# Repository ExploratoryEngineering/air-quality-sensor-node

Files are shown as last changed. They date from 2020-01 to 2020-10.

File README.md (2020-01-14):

# Air quality sensor node

(work in progress)

GPS enabled NB-IoT Sensor node for sampling NO2, NO, O3 and particulate matter.

## OPC-N3 particle sensor
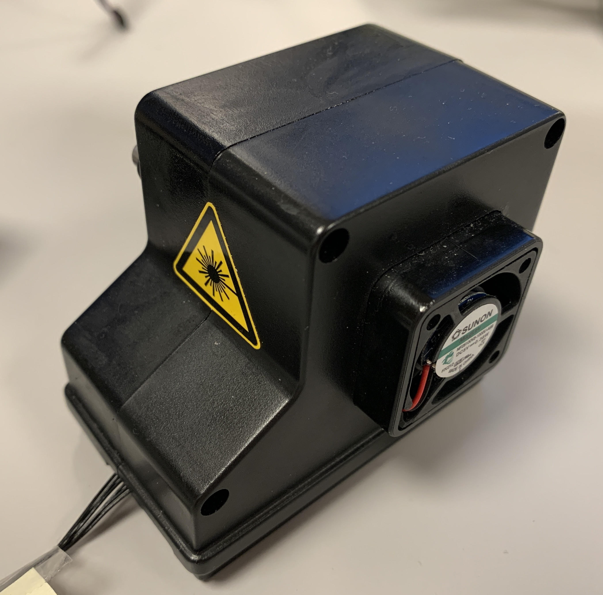
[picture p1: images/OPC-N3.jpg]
OPC-N3 particle sensor


## AFE-3 Analog frontend for NO2, NO and O3 electrochemical sensors
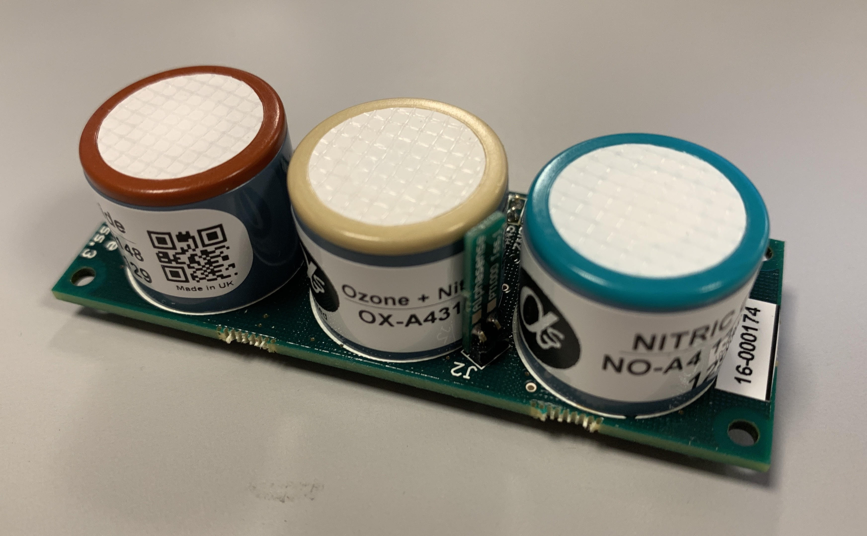
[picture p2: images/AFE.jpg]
Analog frontend and gas sensors


## Vehicle power board
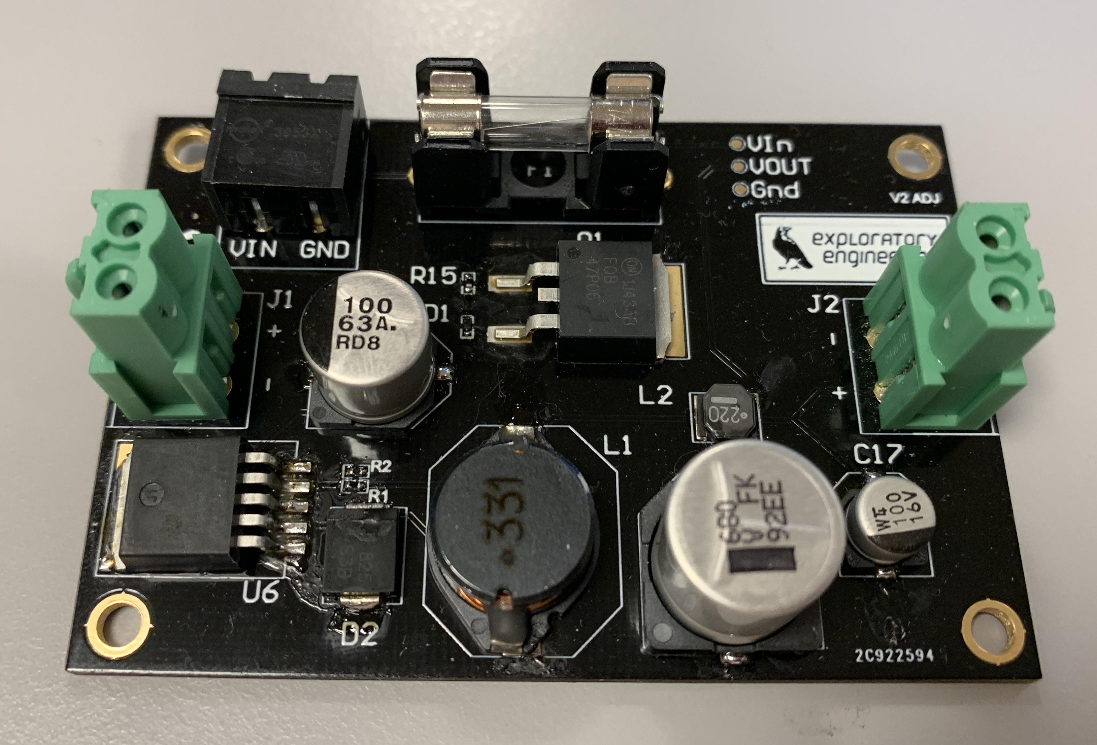
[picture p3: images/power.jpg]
Power board


## EE-NBIoT-02 module
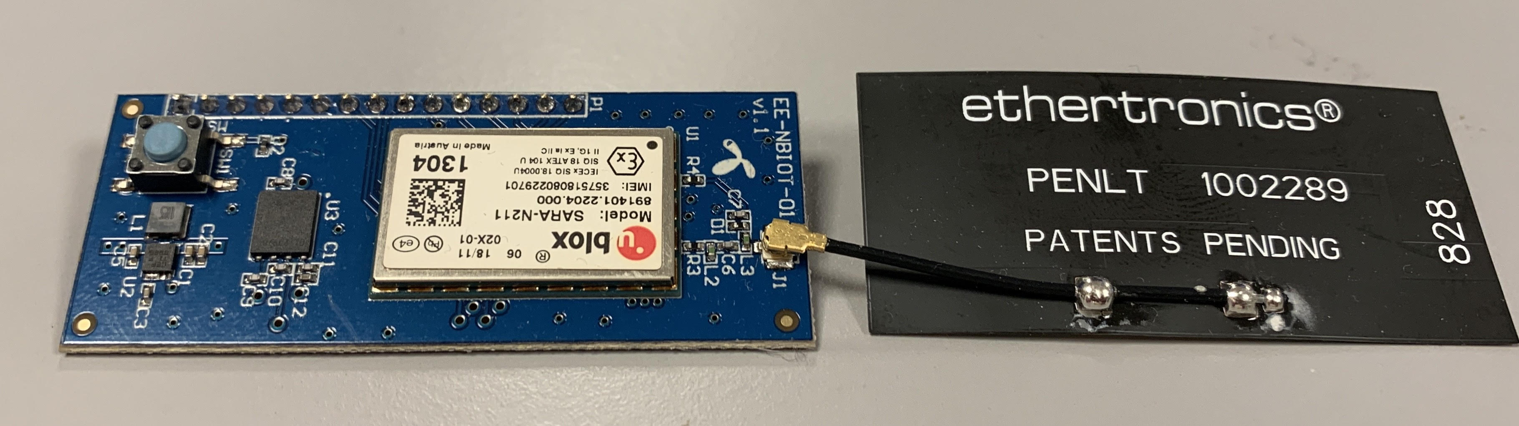
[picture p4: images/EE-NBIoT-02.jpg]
NB-IoT module


## Controller board with nrf52, GPS and ADC
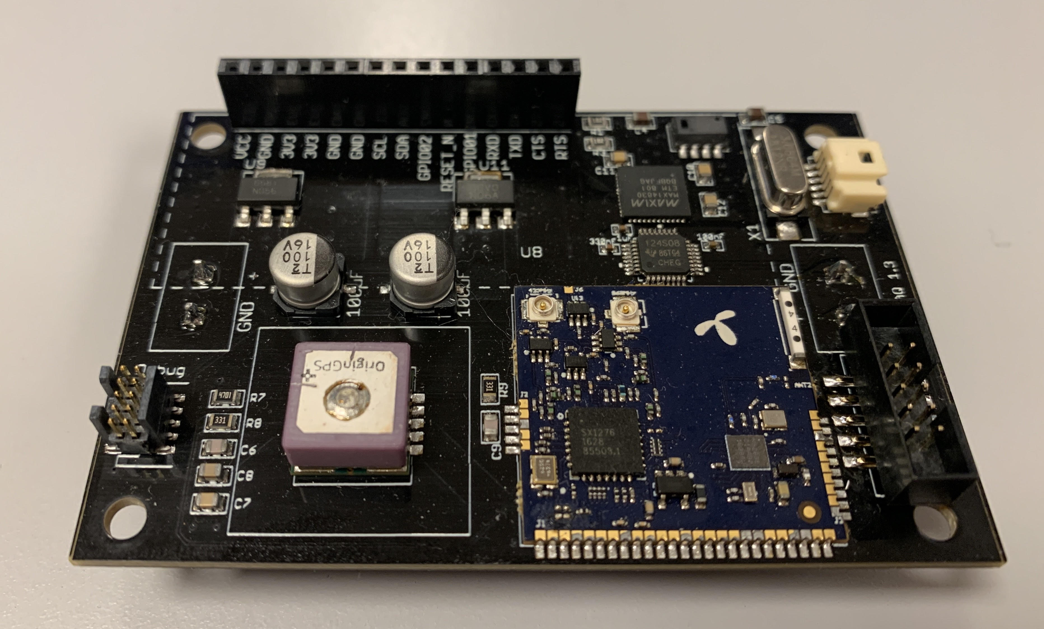
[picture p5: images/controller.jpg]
Controller board


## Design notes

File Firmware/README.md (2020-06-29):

# Air quality sensor node firmware

This project contains firmware for an air quality sensor node

The board is configured for sampling an Alfasense AFE-3 board populated with NO2, NO and O3 sensors, along with temperature, humidity and an OPC-N3 particulate sensor.

Building:

```sh
west update
source ../deps/zephyr/zephyr-env.sh
west build --pristine -b nrf52_pca10040 Firmware
west flash
```
NOTE!  west v0.7 is required for this to work.

## Required tools

To compile protobuf files you need to install protobuf compiler and python bindingds for protobuf.

For MacOS this can be installed with `brew install protobuf` and `pip install protobuf`.
For Linux this can be installed with `apt-get install protobuf-compiler python-protobuf`.

You'll need `make` to build the image. Releases are managed via the `reto` release tool (available at github.com/ExploratoryEngineering/reto)

## Building

You'll need MCUBoot and a key for the application image. If you change the key
you can't deploy the image on existing devices with a different key. A new key
means you'll have to reinstall the bootloader on all your devices.

### Initial setup

Install the "reto" tool:

`go get -u https://github.com/ExploratoryEngineering/reto`

Ensure your Zephyr installation is up and running by running `west build`.

Create a new key and install the bootloader on your device:

```shell
make fwkey
make build_mcuboot
make install_mcuboot
```

### Flashing and debugging

#### Prerequisites

1. Install [JLink](https://www.segger.com/downloads/jlink/) 
2. The ZEPHYR_BASE environment variable has to point to the deps\zephyr
3. Source deps\zephyr\zephyr-env.sh

#### Flashing

1. The target device has to be powered on
2. Connect the EE-04 programmer to a computer via a USB cable
3. Connect the ribbon debug cable between the EE-04 and the target device
4. `make flash`.

#### Debug output

Open a new shell and issue the following command to connect JLink:

```shell
JLinkExe -if swd -device nrf52 -speed 4000 -autoconnect 1
```

Open a second shell and issue the following command to see log output:

```shell
JLinkRTTClient
```

If you have an existing key put it into the `aq_fota.pem` file and skip this step. This is included in `.gitignore` so you won't check it in by accident.

### Message format

The message format uses protobuffers.  You can find these under
**common/protobuf** in this Github repository.  Both the server and
the firmware uses the same protobuffer definition file.

## Enabling FOTA

First commit everything verify the release is read (run `reto status`
to see the current status), the build the release:

`touch CMakeFiles.txt && make`

(this ensures a new build with the updated version number)

Upload firmware image, set version number and assign it to the device in Horde:

```shell
curl -s -HX-API-Token:$(cat .apikey) \
    -XPOST -F image=@build/zephyr/zephyr.signed.bin \
    https://api.nbiot.engineering/collections/$(cat .collectionid)/firmware | jq -r ".imageId" > .firmwareid

curl -XPATCH -d'{"version":"0.0.3"}' -HX-API-Token:$(cat .apikey) \
    https://api.nbiot.engineering/collections/$(cat .collectionid)/firmware/$(cat .firmwareid)

FIRMWAREID=$(cat .firmwareid) curl  -HX-API-Token:$(cat .apikey)\
    -XPATCH -d'{"firmware":{"targetFirmwareId": "${FIRMWAREID}"}}' \
    https://api.nbiot.engineering/collections/$(cat .collectionid)/devices/$(cat .deviceid)

```

Prepare the files `.apikey` with the API token, `.collectionid` and
`.deviceid` with the collection and device ID from Horde. These can be
found and/or created in [The Horde console](https://nbiot.engineering)

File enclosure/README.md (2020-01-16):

# Air quality sensor node

(work in progress)

GPS enabled NB-IoT Sensor node for sampling NO2, NO, O3 and particulate matter. 

# Internal structure (preliminary)

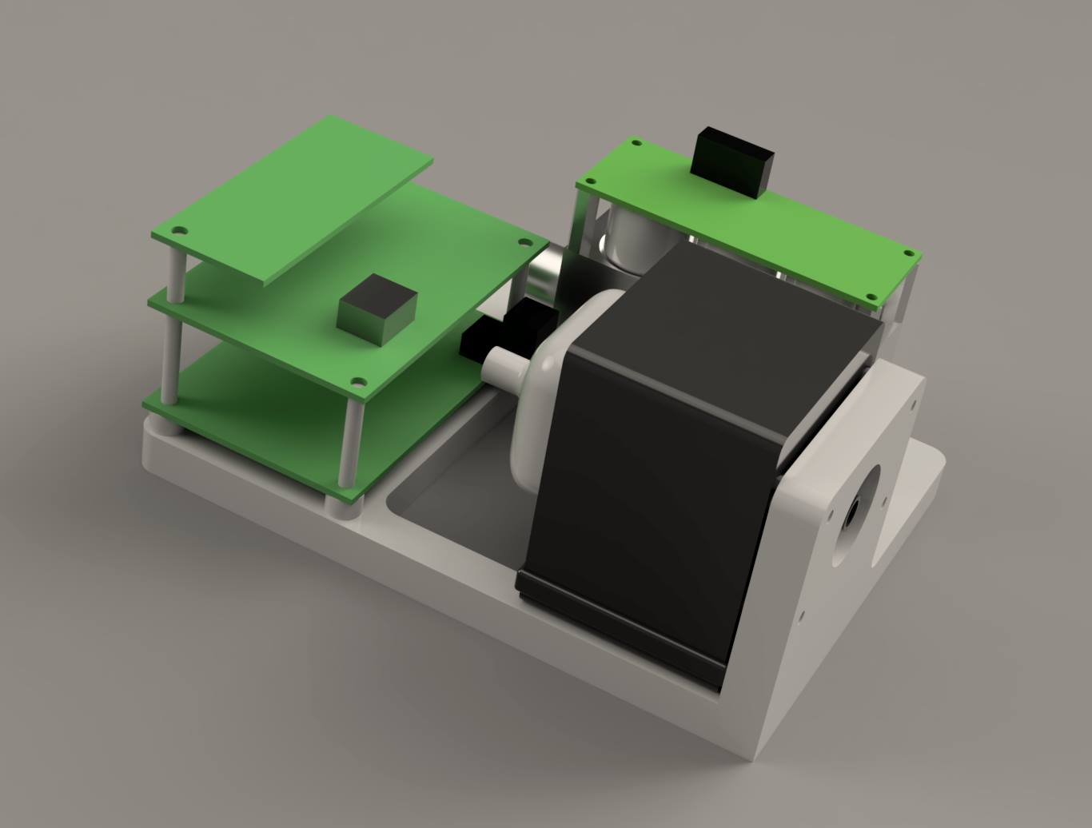
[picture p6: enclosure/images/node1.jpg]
node1


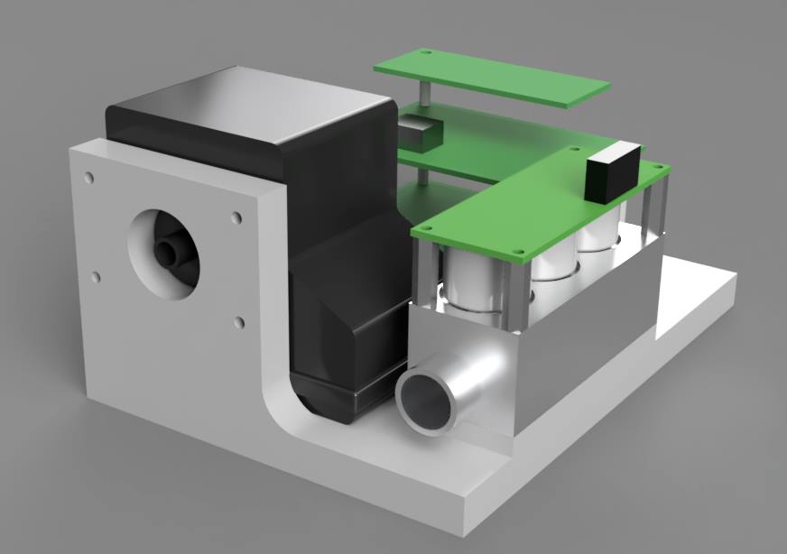
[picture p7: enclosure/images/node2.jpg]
node2


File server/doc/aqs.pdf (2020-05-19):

# AQS Documentation

AQS Documentation

## Contents

Introduction | 3
Building AQS | 5
AQS Usage | 7
Sensors | 8

2

AQS Documentation

## Introduction

The Air Quality Server (AQS) is a lightweight tool that can be used to receive, store and serve air quality data from the third generation air quality sensor from Exploratory Engineering. It can both be run as a more permanent server in a datacenter in order to receive, process, store and pass on data, but it is also designed for ad-hoc experimentation by researchers and integrators. Some care has been taken in order to make both scenarios possible. It should be trivial to download, build and run the server on your personal machine, as well as running it in a datacenter.

Data reception

Currently the server supports two different ways of receiving data - you can either configure it to connect to IoT-GW/Horde and have it listen to the data stream belonging to a given collection.

We are also in the process of developing a solution that will allow the server to use MIC as the source of messages, but this is not supported at the time of writing.

For experimentation purposes it is also possible to use a UDP-based protocol for injecting messages into a running server.

Database storage

The AQS makes use of a local SQLite 3 database where it stores calibration data as well as the messages (datapoints) it has received from the network. We chose to use SQLite 3 as the database as a convenience because the data rates and amounts of data are fairly modest for the number of sensors we are dealing with. At some later point we may support PostgreSQL so that the Air Quality Server can deal with higher volumes.

The choice of embedding the database was made to make life simpler for researchers and people who simply want to experiment with the system, as there is no need to set up and manage a separate database system. Everything is taken care of by the server. The database itself is located in a single file, which makes it easy to copy the data around and perform ad-hoc queries on it using the sqlite3 command line utility.

Open source

The AQS is published under the Apache 2.0 license, and you are encouraged to contribute to its development. Bug reports and feature requests filed through the issue tracking on the Github project

3

AQS Documentation

are welcome. Pull requests with code are even more welcome. The Git repository is located at https: //github.com/exploratoryengineering/air-quality-sensor-node.

4

AQS Documentation

## Building AQS

Check out source from Github

The AQS is hosted on Github at and you can clone it by issuing the command:

git clone https://github.com/ExploratoryEngineering/air-quality-sensor-node.git

This will copy not only the server, but also the hardware designs for the sensor, the firmware source code for the device, and the server. In order to build the server change directory to the server directory.

Fetch dependencies

- Go 1.14 or newer
- Protobuf Compiler version 3.0.0 or newer
- Protobuf Code generator for Go
- SQLite3 libraries

Installing Go

For information on how to install Go, please refer to https://golang.org/doc/install.

Installing Protobuf

To install the protobuf compiler on macOS the easiest route is to use Homebrew and install it with:

brew install protobuf

or on Linux

apt install protobuf-compiler

You then need to install the protobuf code generator for Go, which you can install with the command, which should work on all platforms Go has been ported to:

go install google.golang.org/protobuf/cmd/protoc-gen-go

Installing libsqlite3

On macOS you can install the latest SQLite version (including libraries) using

5

AQS Documentation

brew install sqlite

On Linux you can do this with

apt install libsqlite3-dev

Building AQS with make

We use make to build the server. Per default the Makefile is set up to build the server for macOS. You can either edit the Makefile and change the default valuesfor GOOS and GOARCH tofit the platform you are building on, or you can specify these variables on the command line.

For instance in order to build for Linux you would

GOOS=linux GOARCH=amd64 make

This should produce a bin directory containing a runnable binary called ac. To test that you have succeeded in building it you can run bin/aq and it should produce output that looks something like this:

$ bin/aq -h
Usage:
aq [OPTIONS] <command>

Application Options:
-c, --collection=<collectionID> | Horde collection id to listen to (default: 17dh0cf43jg007)
-d, --db=<file> | Data storage file (default: aq.db)
-v, --verbose

Help Options:
-h, --help | Show this help message

Available commands:
convert Convert calibration data
fetch | Fetch historical data
import | Import a calibration data
list | List calibration data
rm | Remove calibration data
run | Run server
show | Show calibration data for device

6

AQS Documentation

## AQS Usage

** Usage doc **

7

AQS Documentation

## Sensors

Alphasense OPC-N3

For measuring amount of particulate matter present in the air, we use the OPC-N3 (http://www.alphasense.com/index.php/products/optical-particle-counter/) sensor from Alphasense. (http://www.alphasense.com/) This sensor can measure particles from 0.35μm to 40 μm and it will report these in 24 ranges or “bins”. The particle size ranges for each bin can be found in the table on the next page.

8

AQS Documentation

bin from (µm) to (µm)

0 | 0.35 | 0.46
1 | 0.46 | 0.66
2 | 0.66 | 1.0
3 | 1.0 | 1.3
4 | 1.3 | 1.7
5 | 1.7 | 2.3
6 | 2.3 | 3.0
7 | 3.0 | 4.0
8 | 4.0 | 5.2
9 | 5.2 | 6.5
10 | 6.5 | 8.0
11 | 8.0 | 10.0
12 | 10.0 | 12.0
13 | 12.0 | 14.0
14 | 14.0 | 16.0
15 | 16.0 | 18.0
16 | 18.0 | 20.0
17 | 20.0 | 22.0
18 | 22.0 | 25.0
19 | 25.0 | 28.0
20 | 28.0 | 31.0
21 | 31.0 | 34.0
22 | 34.0 | 37.0
23 | 37.0 | 40.0

9

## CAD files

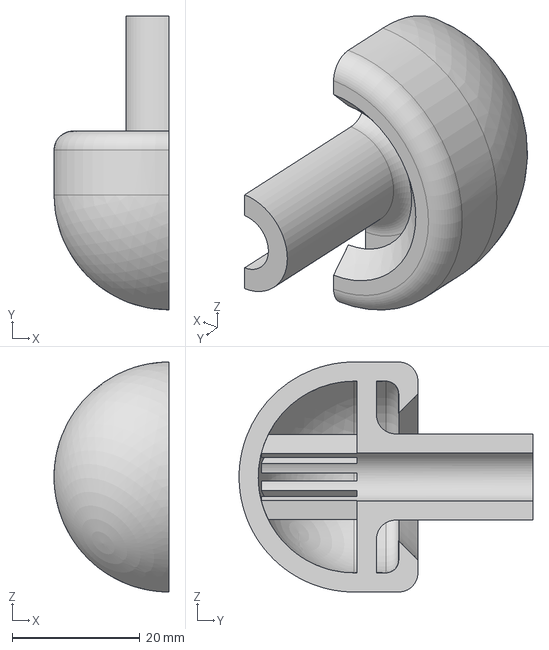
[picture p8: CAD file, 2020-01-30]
enclosure/nozzles/nozzle_bottom.step
18.0 x 46.0 x 36.0 mm

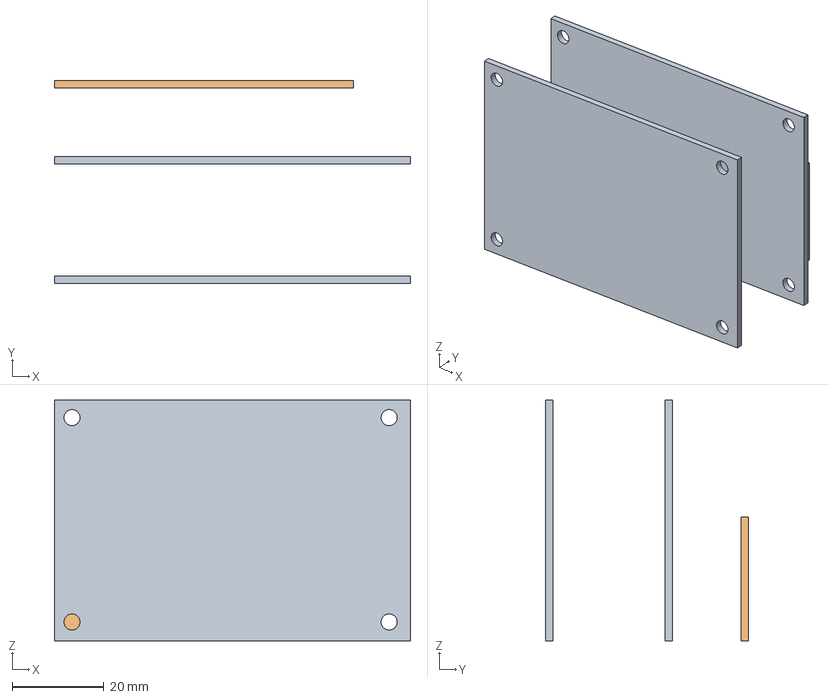
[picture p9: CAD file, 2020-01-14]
enclosure/pcb_stack/SensorPCB_stack.step
77.5 x 44.2 x 52.4 mm
Power board
Sensor Board
EE-NBIOT-01

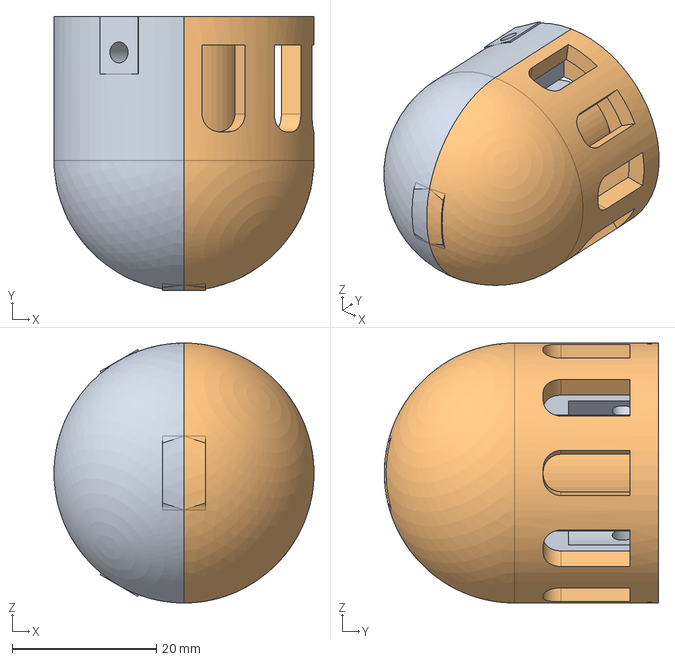
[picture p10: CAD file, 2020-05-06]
enclosure/STEP/PP_Gas_intake.step
36.0 x 38.0 x 36.0 mm
part_b

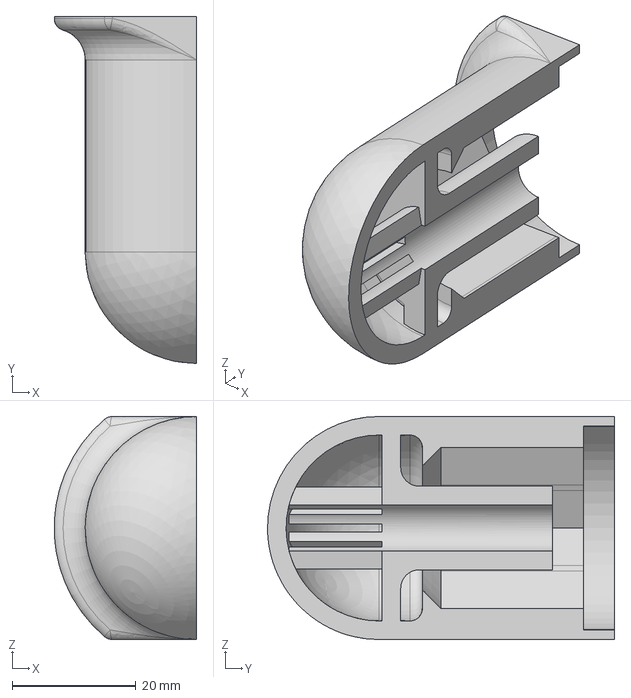
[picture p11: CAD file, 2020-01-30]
enclosure/nozzles/nozzle_top.step
23.0 x 56.0 x 36.0 mm

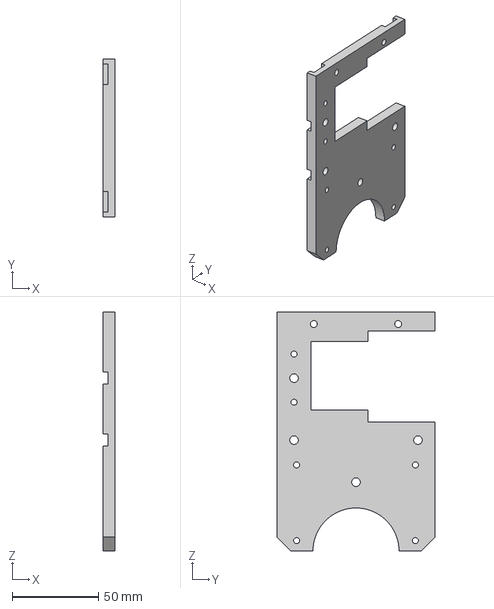
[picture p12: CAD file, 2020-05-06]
enclosure/STEP/PLA_Sensor_frame.step
7.00 x 92.0 x 138.8 mm

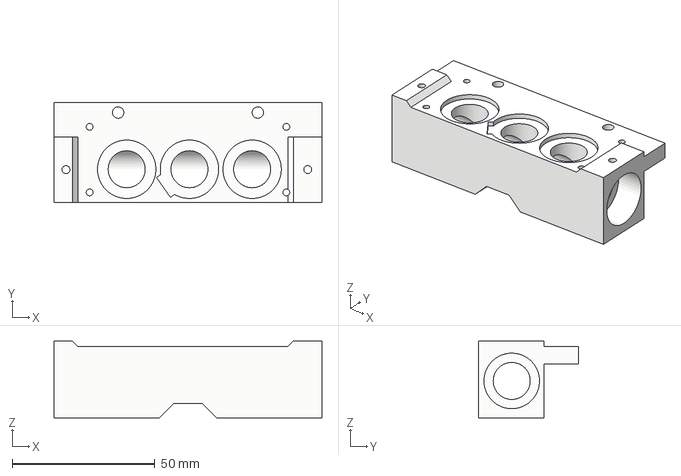
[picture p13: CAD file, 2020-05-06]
enclosure/STEP/PP_AFE_mounting_block.step
94.0 x 35.0 x 27.0 mm

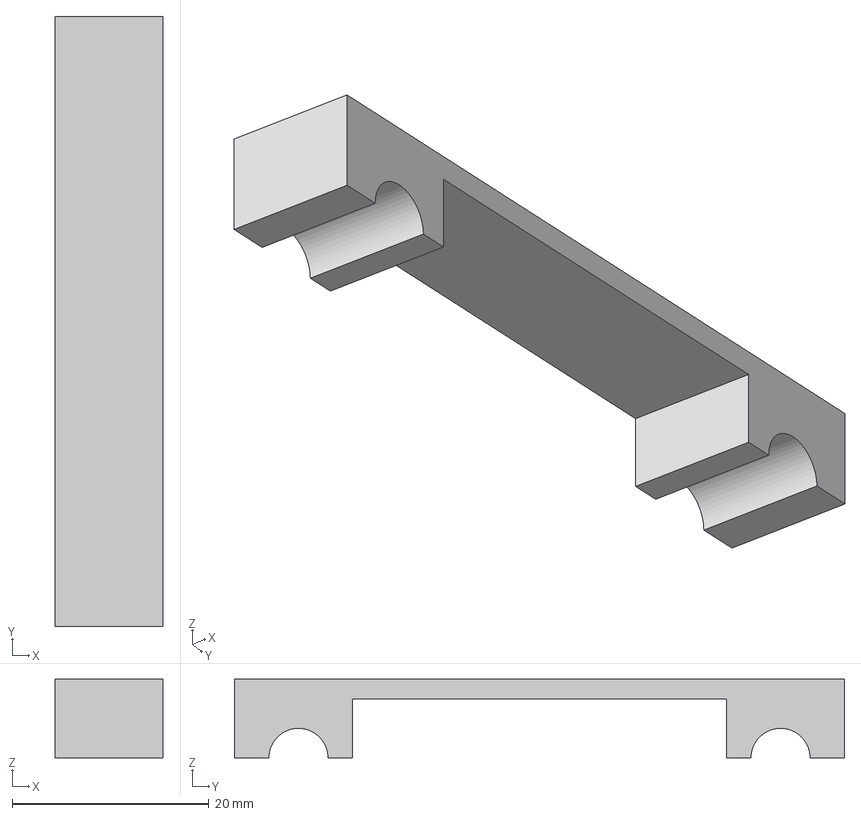
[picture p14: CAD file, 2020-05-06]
enclosure/STEP/PLA_AFE_spacer.step
11.0 x 62.0 x 8.00 mm

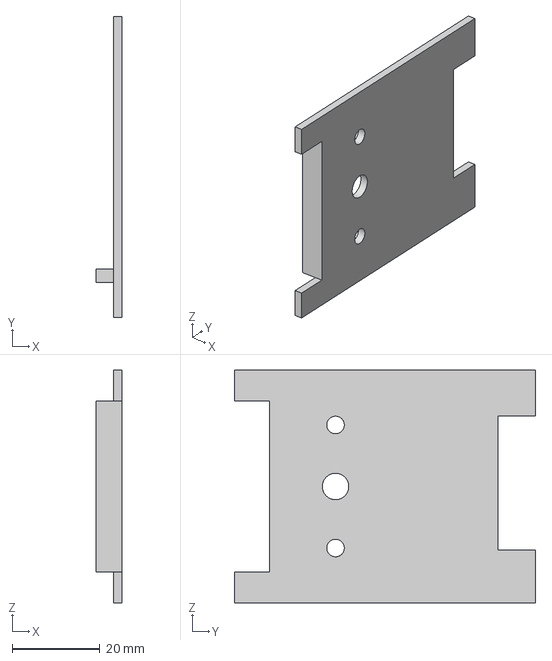
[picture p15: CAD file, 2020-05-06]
enclosure/STEP/PLA_OPC_hood_b.step
6.00 x 68.5 x 53.0 mm

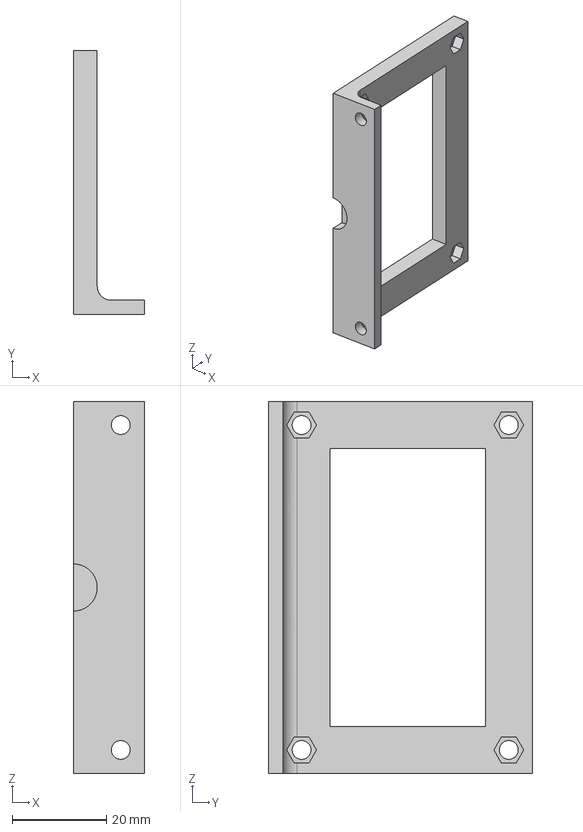
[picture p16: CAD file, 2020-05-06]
enclosure/STEP/PLA_PCB_bracket.step
15.0 x 56.0 x 79.0 mm

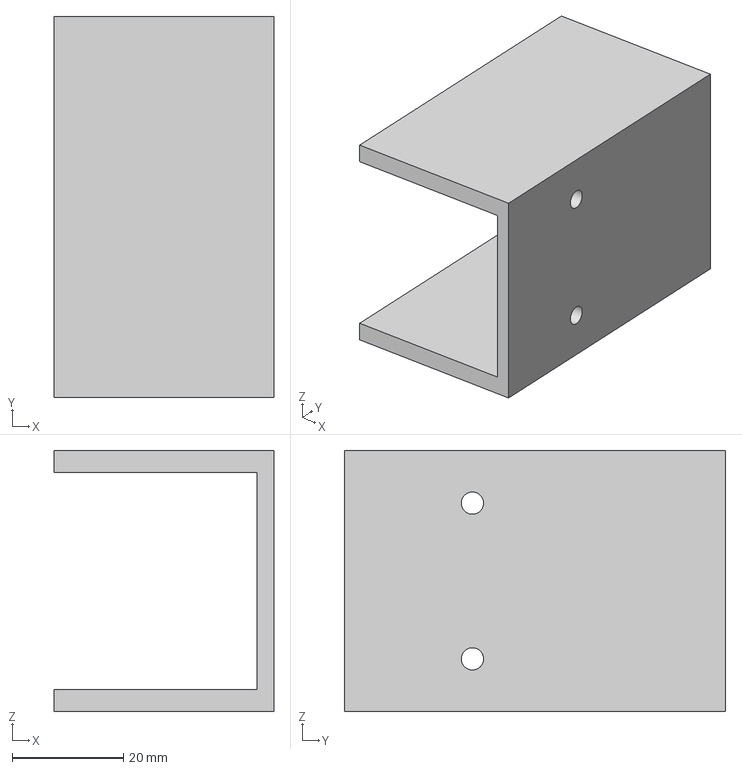
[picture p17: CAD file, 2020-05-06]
enclosure/STEP/PLA_OPC_hood_a.step
39.5 x 68.5 x 47.0 mm

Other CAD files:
enclosure/STEP/PLA_Particle_intake_a.step
enclosure/STEP/PLA_Particle_intake_b.step
enclosure/STL/PLA_AFE_spacer.stl
enclosure/STL/PLA_OPC_hood_a.stl
enclosure/STL/PLA_OPC_hood_b.stl
enclosure/STL/PLA_PCB_bracket.stl
enclosure/STL/PLA_Particle_intake_a.stl
enclosure/STL/PLA_Particle_intake_b.stl
enclosure/STL/PLA_Sensor_frame.stl
enclosure/STL/PP_AFE_mounting_block.stl
enclosure/STL/PP_Gas_intake.stl
enclosure/assembly/Alphasense-A4-AFE-3-way.f3d
enclosure/assembly/OPC-N3.f3d
enclosure/assembly/TP-electric-3310-217-0600.f3d
enclosure/assembly/assembly-2-v10.f3z

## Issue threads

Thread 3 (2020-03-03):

Create server with local database storage

borud, 2020-03-03:
Accept `Sample` messages from Horde and store them to a database.
- [x] Create initial protobuf schema
- [x] Create SQL schema
- [x] Create Horde listener
- [x] Create UDP listener
- [x] Create processing pipeline
- [x] Create simple websockets listener
- [x] Pull older samples from Horde and store them locally

pkkummermo, 2020-03-04:
A lot of inspiration can be taken from https://github.com/ExploratoryEngineering/tkaq as it solves the exact same use case.

borud, 2020-03-08:
@pkkummermo I intend to ste...borrow liberally :-)

Closed 2020-04-06.

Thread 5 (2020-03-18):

Store calibration data in database

borud, 2020-03-18:
- [x] Add table for storing calibration data
- [x] Create import utility that can read calibration data from CSV or JSON
- [ ] Create web interface to add calibration data via browser
- [x] Experiment with OCR of calibration sheets if we can't get calibration data from there (combine with web interface)

borud, 2020-03-29:
Implemented reading calibration data from CSV files that look a bit funky.  Need a better format, but fix that later.

Closed 2020-03-29.

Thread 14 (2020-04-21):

Rewrite calibration data caching logic

borud, 2020-04-21:
Today there's a half baked calibration data cache which is in the wrong place.  Move the caching to the persistence layer.

There should also be a mechanism for detecting if the calibration data has been changed "under our feet" by someone directly modifying the database and trigger a reload.

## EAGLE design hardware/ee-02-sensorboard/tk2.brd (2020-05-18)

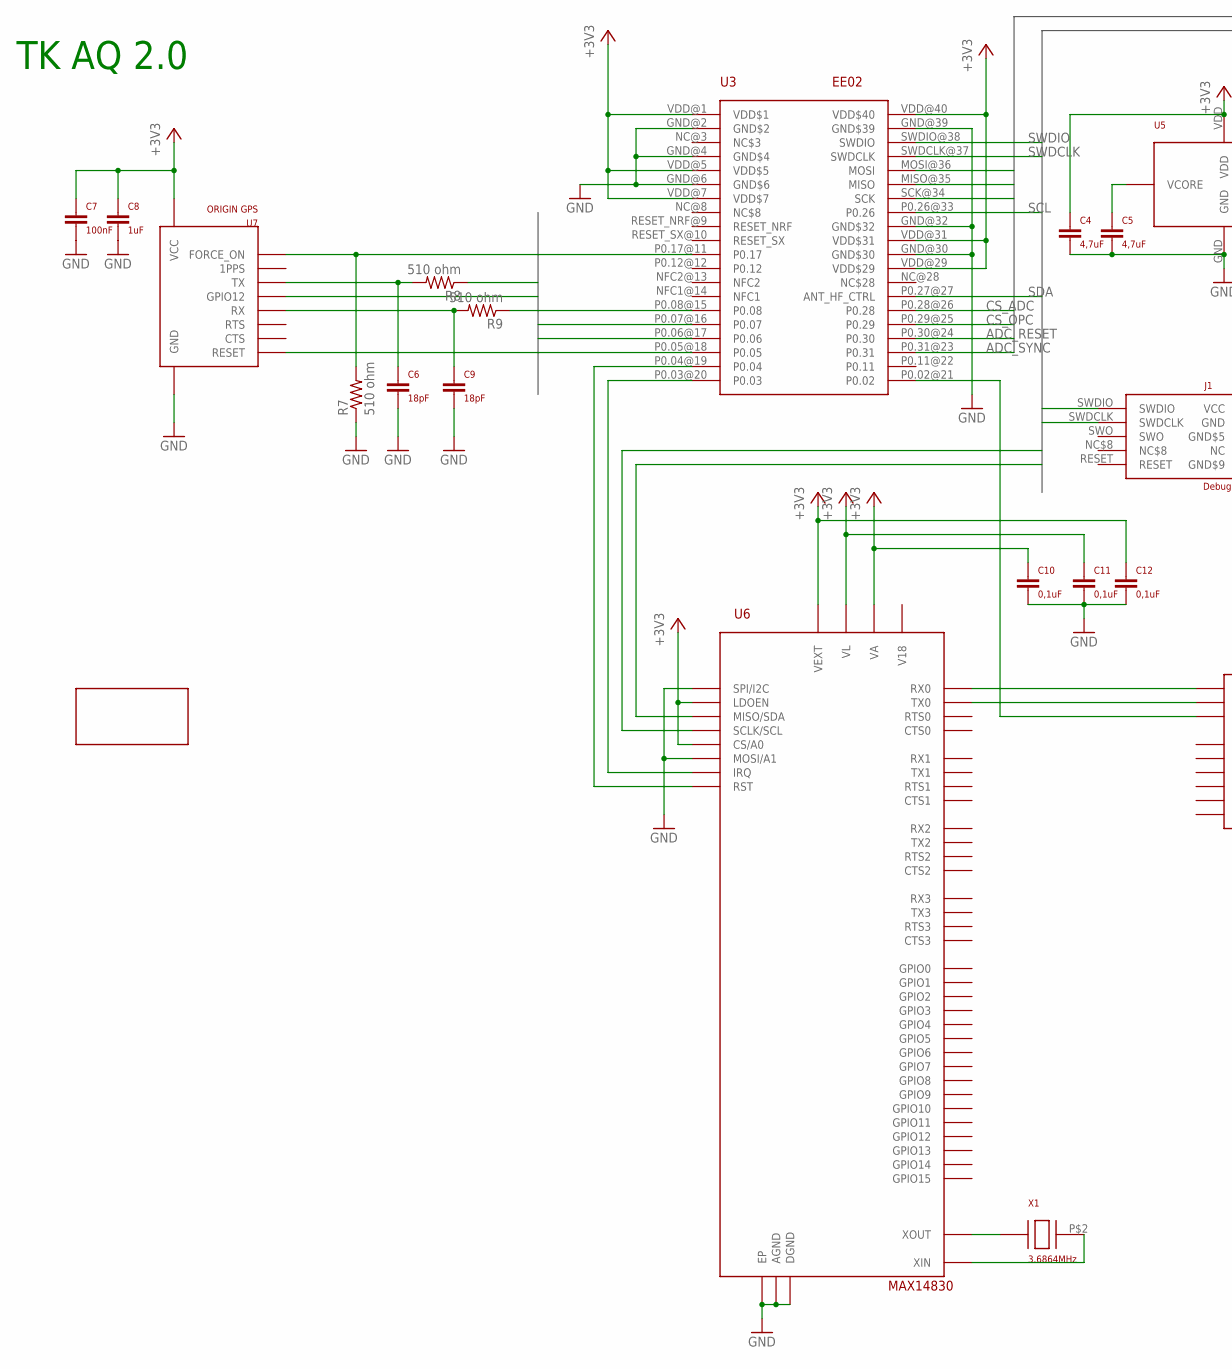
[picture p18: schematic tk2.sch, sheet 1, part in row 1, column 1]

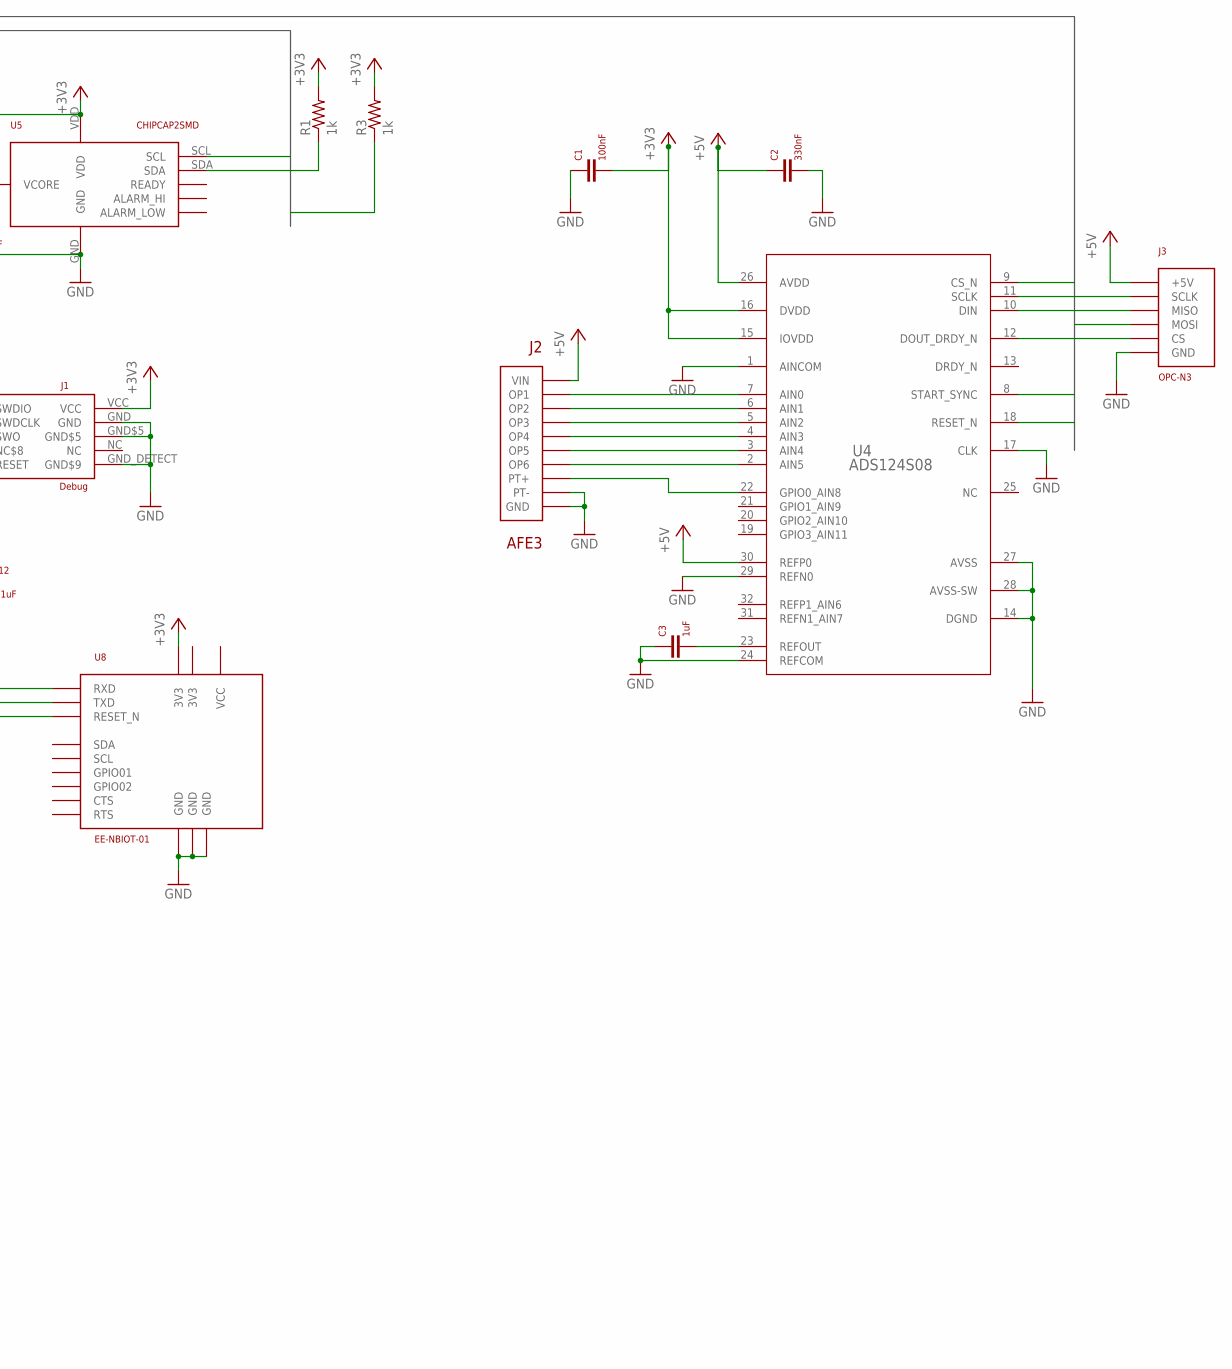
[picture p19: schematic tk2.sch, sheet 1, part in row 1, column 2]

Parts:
C1: 100nF; 0402
C2: 330nF; 0402
C3: 1uF; 0402
C4, C5: 4,7uF; 0805
C6, C9: 18pF; 0805
C7: 100nF; 0805
C8: 1uF; 0805
C10, C11, C12: 0,1uF; 0805
J1: Debug; NRF52-P19-CONNECTOR
J2: AFE3_IDC_CABLE
J3: OPC_N3_CONNECTOR
R1, R3: 1k; 0805
R7, R8, R9: 510 ohm; 0805
U3: EE02; EE02_02
U4: ADS124S08; PBS0032A_N
U5: CHIPCAP2SMD; CHIPCAP2
U6: MAX14830
U7: ORIGIN GPS; ORIGIN_GPS_HORNET_1510
U8: EE-NBIOT-01
U$1: EE_TK_LOGO
X1: CRYSTAL_HC49

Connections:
+3V3: C1.2, C4.1, C7.1, C8.1, C10.1, C11.1, C12.1, J1.VCC, R1.2, R3.2, U3.VDD@1 (VDD$1), U3.VDD@5 (VDD$5), U3.VDD@7 (VDD$7), U3.VDD@29 (VDD$29), U3.VDD@31 (VDD$31), U3.VDD@40 (VDD$40), U4.15 (IOVDD), U4.16 (DVDD), U5.VDD, U6.CS/A0, U6.LDOEN, U6.VA, U6.VEXT, U6.VL, U7.4_VCC (VCC), U8.3V3@3 (3V3); also elsewhere on the board
+5V: C2.1, J2.VIN, J3.+5V, U4.26 (AVDD), U4.30 (REFP0); also elsewhere on the board
ADC_RESET: U3.P0.30@24 (P0.30), U4.18 (RESET_N)
ADC_SYNC: U3.P0.31@23 (P0.31), U4.8 (START_SYNC)
CS_ADC: U3.P0.28@26 (P0.28), U4.9 (CS_N)
CS_OPC: J3.CS, U3.P0.29@25 (P0.29)
FORCE_ON: R7.2, U3.P0.17@11 (P0.17), U7.1_FORCE_ON (FORCE_ON)
GND: C1.1, C2.2, C3.1, C4.2, C5.2, C6.2, C7.2, C8.2, C9.2, C10.2, C11.2, C12.2, J1.GND, J1.GND$5, J1.GND_DETECT (GND$9), J2.GND, J2.PT-, J3.GND, R7.1, U3.GND@2 (GND$2), U3.GND@4 (GND$4), U3.GND@6 (GND$6), U3.GND@30 (GND$30), U3.GND@32 (GND$32), U3.GND@39 (GND$39), U4.1 (AINCOM), U4.14 (DGND), U4.17 (CLK), U4.24 (REFCOM), U4.27 (AVSS), U4.28 (AVSS-SW), U4.29 (REFN0), U5.GND, U6.AGND, U6.DGND, U6.EP, U6.MOSI/A1, U6.SPI/I2C, U7.5_GND (GND), U8.GND@2 (GND), U8.GND@5 (GND), U8.GND@6 (GND); also elsewhere on the board
MISO: J3.MISO, U3.MISO@35 (MISO), U4.12 (DOUT_DRDY_N)
MOSI: J3.MOSI, U3.MOSI@36 (MOSI), U4.10 (DIN)
unnamed: C5.1, U5.VCORE
unnamed: C3.2, U4.23 (REFOUT)
unnamed: U6.RX0, U8.RXD
unnamed: U6.TX0, U8.TXD
unnamed: C6.1, R8.2, U7.3_TX (TX)
unnamed: C9.1, R9.2, U7.10_RX (RX)
unnamed: J2.OP1, U4.7 (AIN0)
unnamed: J2.OP2, U4.6 (AIN1)
unnamed: J2.OP3, U4.5 (AIN2)
unnamed: J2.OP4, U4.4 (AIN3)
unnamed: U3.P0.03@20 (P0.03), U6.IRQ
unnamed: U3.P0.04@19 (P0.04), U6.RST
unnamed: U3.P0.02@21 (P0.02), U8.RESET_N
unnamed: U6.XOUT, X1.P$1
unnamed: U6.XIN, X1.P$2
unnamed: J2.OP5, U4.3 (AIN4)
unnamed: J2.OP6, U4.2 (AIN5)
unnamed: J2.PT+, U4.22 (GPIO0_AIN8)
RESET: U3.P0.06@17 (P0.06), U7.8_RESET (RESET)
RX: R9.1, U3.P0.07@16 (P0.07)
SCL: R1.1, U3.P0.26@33 (P0.26), U5.SCL, U6.SCLK/SCL
SCLK: J3.SCLK, U3.SCK@34 (SCK), U4.11 (SCLK)
SDA: R3.1, U3.P0.27@27 (ANT_HF_CTRL), U5.SDA, U6.MISO/SDA
SWDCLK: J1.SWDCLK, U3.SWDCLK@37 (SWDCLK)
SWDIO: J1.SWDIO, U3.SWDIO@38 (SWDIO)
TX: R8.1, U3.P0.08@15 (P0.08)
WAKE_UP: U3.P0.05@18 (P0.05), U7.6_GPIO12 (GPIO12)

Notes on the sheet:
TK AQ 2.0

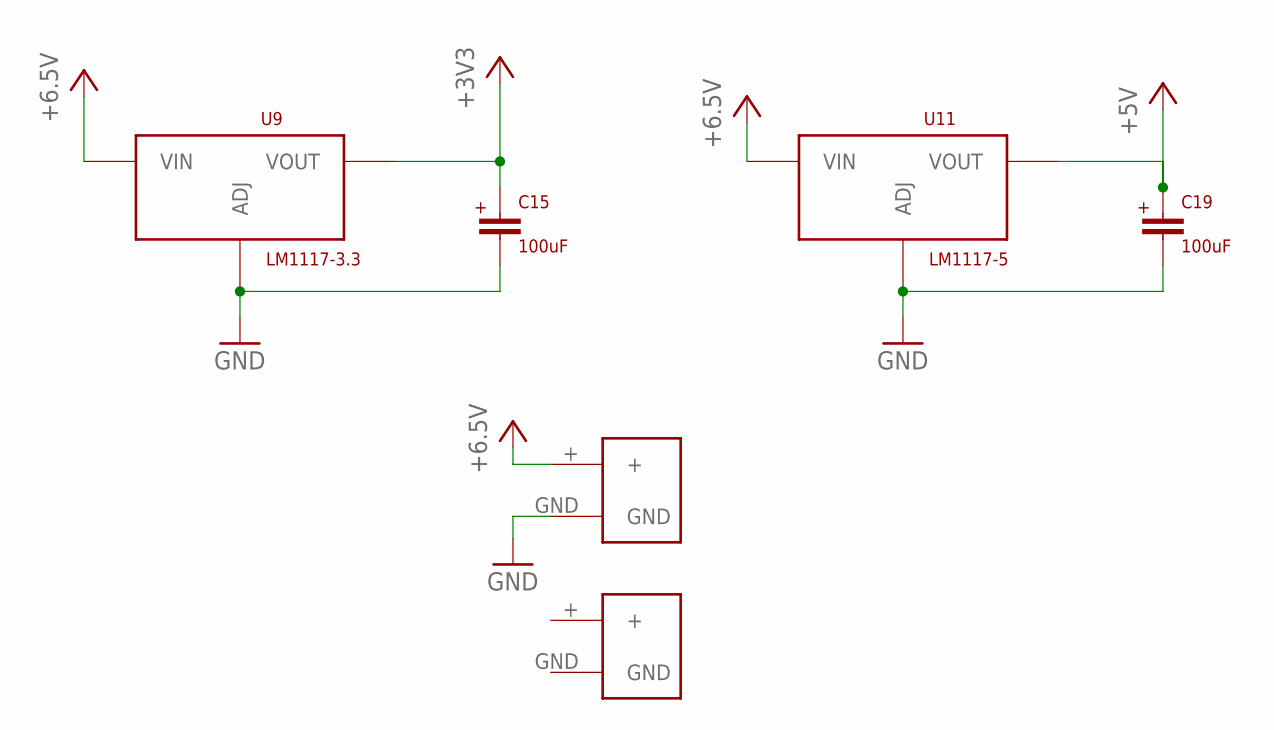
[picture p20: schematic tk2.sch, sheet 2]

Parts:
C15, C19: 100uF; ALUMINUM_WURTH_100UF_865080243007
U9: LM1117-3.3; LM1117
U11: LM1117-5; LM1117
U$2, U$3: PHOENIX_CONTACT_MSTBVA_2_5

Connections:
+3V3: C15.+, U9.VOUT$1 (VOUT), U9.VOUT$2 (VOUT); also elsewhere on the board
+5V: C19.+, U11.VOUT$1 (VOUT), U11.VOUT$2 (VOUT); also elsewhere on the board
+6.5V: U9.VIN, U11.VIN, U$2.+
GND: C15.-, C19.-, U9.GND (ADJ), U11.GND (ADJ), U$2.GND; also elsewhere on the board

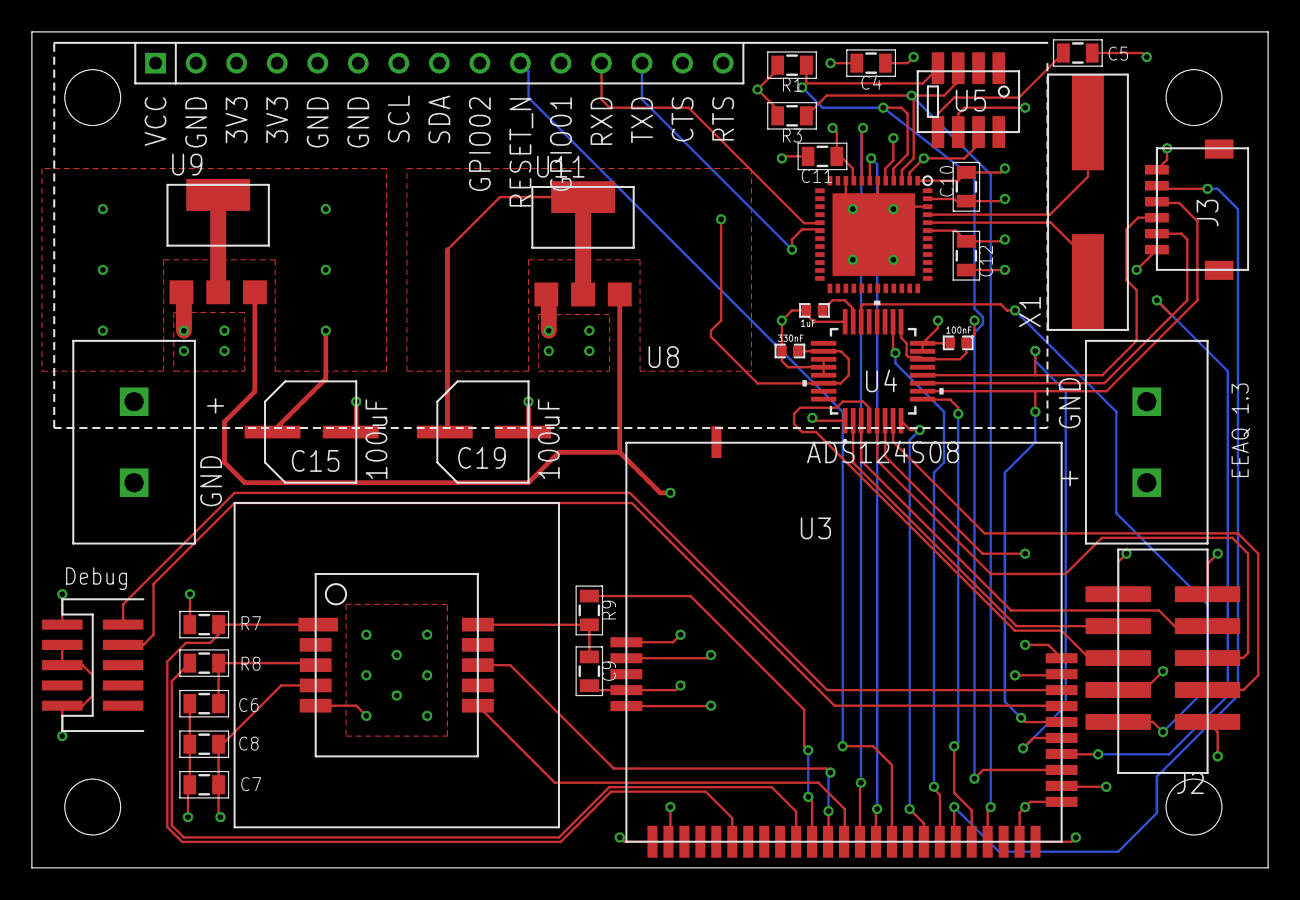
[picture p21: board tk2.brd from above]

Board: 4 copper layers, 77.5 x 52.4 mm, 34 parts (1 on the bottom side), 38 nets.

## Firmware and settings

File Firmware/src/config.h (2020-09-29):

#ifndef _CONFIG_H_
#define _CONFIG_H_

#define APN_QUERY_RETRY_COUNT 	30
#define APN_RETRY_DELAY_MS		3000	

#define PING_RETRIES            30
#define PING_RETRY_DELAY_MS		3000	

#define NVS_APN_COUNT 4

// Default COAP parameters
#define DEFAULT_FOTA_COAP_REPORT_PATH   "u"
#define DEFAULT_FOTA_COAP_UPDATE_PATH   "fw"
#define DEFAULT_FOTA_COAP_PORT 5683

// Force reboot after 2 hours. This wil trigger a new scan for active APNs
#define UPTIME_FORCE_REBOOT_LIMIT_SECONDS 60 * 120

#include "config_message.h"
#include "aqconfig.pb.h"

void init_config_nvs();
void select_active_apn();
bool select_ping_apn();
int save_apn_config();

#endif // _CONFIG_H_

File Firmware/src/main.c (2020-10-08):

/*
**   Copyright 2020 Telenor Digital AS
**
**  Licensed under the Apache License, Version 2.0 (the "License");
**  you may not use this file except in compliance with the License.
**  You may obtain a copy of the License at
**
**      http://www.apache.org/licenses/LICENSE-2.0
**
**  Unless required by applicable law or agreed to in writing, software
**  distributed under the License is distributed on an "AS IS" BASIS,
**  WITHOUT WARRANTIES OR CONDITIONS OF ANY KIND, either express or implied.
**  See the License for the specific language governing permissions and
**  limitations under the License.
*/

#include <zephyr.h>
#include <stdio.h>
#include <logging/log.h>
#include <net/socket.h>
#include <misc/reboot.h>
#include <drivers/watchdog.h>

#include "gps.h"
#include "messagebuffer.h"
#include "version.h"
#include "init.h"
#include "chipcap2.h"
#include "n2_offload.h"
#include "fota.h"
#include "comms.h"
#include "config.h"
#include "config_message.h"


#define LOG_LEVEL CONFIG_MAIN_LOG_LEVEL
LOG_MODULE_REGISTER(MAIN);

#define SEND_INTERVAL_SEC 30
#define FOTA_CHECK_INTERVAL_SEC 500

#define FOTA_COUNTER (FOTA_CHECK_INTERVAL_SEC / SEND_INTERVAL_SEC)

#define MAX_SEND_BUFFER 450
static uint8_t buffer[MAX_SEND_BUFFER];

#define MAX_COMMAND_BUFFER 256
static uint8_t command_buffer[MAX_COMMAND_BUFFER];

extern char CURRENT_COAP_BUFFER[128];
extern apn_config CURRENT_APN_CONFIG;


void dump_buffer(uint8_t * buf, int len)
{
	LOG_INF("Dumping buffer: %d bytes", len);
	for (int i=0; i<len; i++)
	{
		LOG_INF("%02X", *buf++);
	}
}



// Watchdog
#define WDT_DEV_NAME DT_WDT_0_NAME
struct device *wdt;
int wdt_channel_id;


static void wdt_callback(struct device *wdt_dev, int channel_id)
{
	LOG_WRN("Watchdog timer expired. Rebooting in 1 second");
	k_sleep(1000);
	sys_reboot(0);
}


void watchdog_init()
{
	int err;
	struct wdt_timeout_cfg wdt_config;

	LOG_INF("Initializing watchdog");

	wdt = device_get_binding(WDT_DEV_NAME);
	if (!wdt) {
		printk("Cannot get WDT device\n");
		return;
	}

	// Reset SoC when watchdog timer expires.
	wdt_config.flags = WDT_FLAG_RESET_SOC;

	// Expire watchdog after two hours. 
	wdt_config.window.min = 0U;
	wdt_config.window.max = 7200000U;

	// Set up watchdog callback. Jump into it when watchdog expired.
	wdt_config.callback = wdt_callback;

	wdt_channel_id = wdt_install_timeout(wdt, &wdt_config);
	if (wdt_channel_id == -ENOTSUP) 
	{
		wdt_config.callback = NULL;
		wdt_channel_id = wdt_install_timeout(wdt, &wdt_config);
	}
	if (wdt_channel_id < 0) 
	{
		LOG_ERR("Watchdog install error");
		return;
	}

	err = wdt_setup(wdt, 0);
	if (err < 0) 
	{
		LOG_ERR("Watchdog setup error\n");
		return;
	}

	LOG_INF("Watchdog channel id: %d", wdt_channel_id);
}


void do_the_hetzner_ping()
{
	LOG_INF("----------------------");
	LOG_INF("Doing the Hetzner ping");
	LOG_INF("----------------------");

	// Select temporary APN. Bail out if we can't make contact
	if (!select_ping_apn())
		return;

	// Create socket
	int sock = socket(AF_INET, SOCK_DGRAM, IPPROTO_UDP);
	if (sock < 0)
	{
		LOG_ERR("Error opening socket: %d", sock);
		k_sleep(1000);
		sys_reboot(0);
	}
	
	static struct sockaddr_in remote_addr_ping = {
		sin_family : AF_INET,
	};
	remote_addr_ping.sin_port = htons(1234);
	net_addr_pton(AF_INET, CURRENT_COAP_BUFFER, &remote_addr_ping.sin_addr);

	char PING_BUFFER[128];

	int ping_bytes = 0;
	if (!encode_ping(PING_BUFFER, sizeof(PING_BUFFER), &ping_bytes))
	{
		LOG_ERR("Failed encoding PING message. Bailing out");
		return;
	}
	LOG_INF("Encoded protobuf PING: %d bytes", ping_bytes);

	for (int i=0; i<PING_RETRIES; i++) 
	{
		LOG_INF("PING attempts: %d", i);
		int err = sendto(sock, PING_BUFFER, ping_bytes, 0, (struct sockaddr *)&remote_addr_ping, sizeof(remote_addr_ping));
		if (err < 0)
		{
			LOG_ERR("Unable to send data to PING server: %d", err);
		}
		k_sleep(1000);
		int received = recvfrom(sock, command_buffer, sizeof(command_buffer), 0, NULL, NULL);
		if (received > 0)
		{
			LOG_INF("----------------------------------------------");
			LOG_INF("RECEIVED CONFIGURAION request from PING server");
			LOG_INF("----------------------------------------------");
			// A correctly decoded message that contains parameters that differ from those
			// stored in NVS will force a reboot and new APN scan
			// a negative return value indicates invalid or unchanged parameters,
			// which means we don't need to retry
			int rc = decode_config_message(command_buffer, received);
			if (rc != 0)
			{
				close (sock);
				return;
			}
		}
		k_sleep(PING_RETRY_DELAY_MS);
	}

	LOG_INF("PING timeout. No reply from PING server");

	close (sock);
}



void main(void)
{
 	init_board();
	watchdog_init();

	k_sleep(1000);

	LOG_INF("This is the AQ node with version %s (%s)", AQ_VERSION, AQ_NAME);

	cc2_init();
	gps_init();
	opc_init();

	LOG_INF("Waiting for modem");
	wait_for_sockets();
	LOG_DBG("Ready to run");

	do_the_hetzner_ping();

	select_active_apn();

	fota_init();
	if (fota_run())
	{
		k_sleep(1000);
	}

	// Create config socket
	int config_sock = socket(AF_INET, SOCK_DGRAM, IPPROTO_UDP);
	if (config_sock < 0)
	{
		LOG_ERR("Error opening socket: %d", config_sock);
		k_sleep(1000);
		sys_reboot(0);
	}
	
	static struct sockaddr_in remote_addr_config = {
		sin_family : AF_INET,
	};
	remote_addr_config.sin_port = htons(1234);
	net_addr_pton(AF_INET, CURRENT_COAP_BUFFER, &remote_addr_config.sin_addr);


	
	// Main loop
	int fota_interval = 0;
	while (true)
	{
		// modem_restart_without_triggering_network_signalling_storm_but_hopefully_picking_up_the_correct_cell___maybe();

		wdt_feed(wdt, wdt_channel_id); // Tickle and feed the watchdog

		// Check if we have received any configuration messsages via the config port
		int received = recvfrom(config_sock, command_buffer, sizeof(command_buffer), 0, NULL, NULL);
		if (received > 0)
		{
			LOG_INF("---------------------------------");
			LOG_INF("CONFIG message received. %d bytes", received);
			LOG_INF("---------------------------------");
			decode_config_message(command_buffer, received);
		}

		// Create send socket
		int sock = socket(AF_INET, SOCK_DGRAM, IPPROTO_UDP);
		if (sock < 0)
		{
			LOG_ERR("Error opening socket: %d", sock);
			k_sleep(1000);
			sys_reboot(0);
		}
		
		static struct sockaddr_in remote_addr = {
			sin_family : AF_INET,
		};
		remote_addr.sin_port = htons(1234);
		net_addr_pton(AF_INET, CURRENT_COAP_BUFFER, &remote_addr.sin_addr);



		LOG_DBG("Sampling sensors");
		SENSOR_NODE_MESSAGE last_message;

		opc_n3_sample_data();
		opc_n3_get_sample(&last_message.opc_sample);

		adc_sample_data();
		adc_get_sample(&last_message.afe3_sample);

		cc2_sample_data();
		cc2_get_sample(&last_message.cc2_sample);

		gps_get_sample(&last_message.gps_fix);

		last_message.uptime = k_uptime_get() / 1000;

		int len = mb_encode(&last_message, buffer, MAX_SEND_BUFFER);
		LOG_DBG("Sample complete, encoded buffer = %d bytes", len);


	#if 0
		mb_hex_dump_message(buffer, len);
	#endif

/*		// Ugly last minute hack -
		coap_buffer[0] = 0x40;
		coap_buffer[1] = 0x02;
		coap_buffer[2] = 0x28;
		coap_buffer[3] = 0x90;
		coap_buffer[4] = 0xbb;
		coap_buffer[5] = 0x72;
		coap_buffer[6] = 0x65;
		coap_buffer[7] = 0x71;
		coap_buffer[8] = 0x75;
		coap_buffer[9] = 0x65;
		coap_buffer[10] = 0x73;
		coap_buffer[11] = 0x74;
		coap_buffer[12] = 0x2f;
		coap_buffer[13] = 0x75;
		coap_buffer[14] = 0x72;
		coap_buffer[15] = 0x69;
		coap_buffer[16] = 0xff;

		int header_len = 17;
		memcpy(&coap_buffer[17], buffer, len);
		remote_addr.sin_port = htons(DEFAULT_FOTA_COAP_PORT);
		net_addr_pton(AF_INET, CURRENT_COAP_BUFFER, &remote_addr.sin_addr);
		*/
		int err = sendto(sock, buffer, len, 0, (struct sockaddr *)&remote_addr, sizeof(remote_addr));
//		err = sendto(sock, coap_buffer, len+header_len, 0, (struct sockaddr *)&remote_addr, sizeof(remote_addr));
		if (err < 0)
		{
			LOG_ERR("Unable to send data: %d", err);
			k_sleep(5000);
			sys_reboot(0);
		}
		
		LOG_DBG("Done sending, sending again in %d seconds", SEND_INTERVAL_SEC);
		k_sleep(SEND_INTERVAL_SEC * K_MSEC(1000));

		fota_interval++;
		if (fota_interval > FOTA_COUNTER)
		{
			LOG_DBG("Check for new firmware");
			fota_interval = 0;
			if (fota_run())
			{
				k_sleep(1000);
			}
		}

		close (sock);

		// Force a reboot once a day. This wil implicitly trigger a new APN scan
		int uptime_seconds = k_uptime_get() / 1000;
		LOG_INF("Uptime: %d seconds", uptime_seconds);
		if (uptime_seconds > UPTIME_FORCE_REBOOT_LIMIT_SECONDS)
		{
			LOG_INF("REBOOTING");
			k_sleep(2000);
			sys_reboot(0);
		}
		
#if 0
			mb_dump_message(&last_message);
#endif
	}

}

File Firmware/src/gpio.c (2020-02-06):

/*
**   Copyright 2020 Telenor Digital AS
**
**  Licensed under the Apache License, Version 2.0 (the "License");
**  you may not use this file except in compliance with the License.
**  You may obtain a copy of the License at
**
**      http://www.apache.org/licenses/LICENSE-2.0
**
**  Unless required by applicable law or agreed to in writing, software
**  distributed under the License is distributed on an "AS IS" BASIS,
**  WITHOUT WARRANTIES OR CONDITIONS OF ANY KIND, either express or implied.
**  See the License for the specific language governing permissions and
**  limitations under the License.
*/

#include <zephyr.h>
#include "gpio.h"
#include "pinout.h"
#include <zephyr.h>
#include <device.h>
#include <gpio.h>
#include <misc/util.h>
#include <stdio.h>

#define LOG_LEVEL CONFIG_EEGPIO_LEVEL
#include <logging/log.h>
LOG_MODULE_REGISTER(EEGPIO);

static struct device *gpio_dev = NULL;

int ConfigureOutputPin(u32_t pin)
{
    int ret = gpio_pin_configure(gpio_dev, pin, (GPIO_DIR_OUT));
    if (ret)
    {
        LOG_ERR("Error configuring pin # %d as output pin", pin);
    }
    return ret;
}

int ConfigureInputPin(u32_t pin)
{
    int ret = gpio_pin_configure(gpio_dev, pin, (GPIO_DIR_IN));
    if (ret)
    {
        LOG_ERR("Error configuring pin # %d as input pin", pin);
    }
    return ret;
}
#define RESET_PIN_PULLER_MIGHT_NOT_NEED 100
static void init_GPIO()
{
    LOG_INF("Configuring pins");

    // CS_SX1276
    LOG_DBG("Disable ANT_HF_CONTROL on EE-02");
    ConfigureOutputPin(CS_SX1276);
    gpio_pin_write(gpio_dev, CS_SX1276, 1);

    // ADC
    LOG_DBG("Configuring ADC");
    ConfigureOutputPin(CS_ADC);
    ConfigureOutputPin(ADC_SYNC);
    ConfigureOutputPin(ADC_RESET);
    // ConfigureOutputPin(CKEN_PIN);
    // ConfigureOutputPin(DRDY_PIN);
    gpio_pin_write(gpio_dev, ADC_SYNC, 0);
    gpio_pin_write(gpio_dev, ADC_RESET, 0);
    k_sleep(RESET_PIN_PULLER_MIGHT_NOT_NEED);
    gpio_pin_write(gpio_dev, ADC_RESET, 1);
    gpio_pin_write(gpio_dev, CS_ADC, 1);
    // gpio_pin_write(CK_EN, 0);

    // OPC-N3
    LOG_DBG("Configuring OPC-N3");
    ConfigureOutputPin(CS_OPC);
    gpio_pin_write(gpio_dev, CS_OPC, 1);

    // GPS
    LOG_DBG("Configuring GPS");
    ConfigureOutputPin(GPS_FORCE_ON);
    ConfigureOutputPin(GPS_TX);
    ConfigureOutputPin(GPS_RESET);
    ConfigureOutputPin(GPS_WAKE_UP);
    ConfigureInputPin(GPS_RX);

    gpio_pin_write(gpio_dev, GPS_RESET, 0);
    gpio_pin_write(gpio_dev, GPS_RESET, 1);
    gpio_pin_write(gpio_dev, GPS_FORCE_ON, 0);
    k_sleep(RESET_PIN_PULLER_MIGHT_NOT_NEED);
    gpio_pin_write(gpio_dev, GPS_FORCE_ON, 1);

    // MAX14830
    LOG_DBG("Configuring MAX14830");
    ConfigureOutputPin(MAX14830_RESET);
    gpio_pin_write(gpio_dev, MAX14830_RESET, 1);
    gpio_pin_write(gpio_dev, MAX14830_RESET, 0);
    k_sleep(RESET_PIN_PULLER_MIGHT_NOT_NEED);
    gpio_pin_write(gpio_dev, MAX14830_RESET, 1);
    k_sleep(RESET_PIN_PULLER_MIGHT_NOT_NEED);
    int ret = gpio_pin_configure(gpio_dev, MAX14830_IRQ, GPIO_DIR_IN | GPIO_PUD_PULL_UP);
    if (ret)
    {
        LOG_ERR("Error configuring interrupt for pin # %d (MAX14830): %d", MAX14830_IRQ, ret);
    }

    // EE-NBIOT-01/02
    ConfigureOutputPin(EE_NBIOT_01_RESET);
    gpio_pin_write(gpio_dev, EE_NBIOT_01_RESET, 1);

    LOG_DBG("finished configuring pins");
}

struct device *get_GPIO_device()
{
    if (gpio_dev == NULL)
    {
        gpio_dev = device_get_binding(DT_GPIO_P0_DEV_NAME);
        if (!gpio_dev)
        {
            LOG_ERR("Can't find device %s!", log_strdup(DT_GPIO_P0_DEV_NAME));
            return NULL;
        }
        init_GPIO();
    }
    return gpio_dev;
}

void gps_reset()
{
    LOG_DBG("GPS reset...");

    gpio_pin_write(gpio_dev, GPS_RESET, 0);
    gpio_pin_write(gpio_dev, GPS_RESET, 1);
    gpio_pin_write(gpio_dev, GPS_FORCE_ON, 0);
    k_sleep(RESET_PIN_PULLER_MIGHT_NOT_NEED);
    gpio_pin_write(gpio_dev, GPS_FORCE_ON, 1);
}

int UnSelect(u32_t pin)
{
    int ret = gpio_pin_write(gpio_dev, pin, 1);
    if (ret)
    {
        LOG_ERR("Error writing to pin # %d", pin);
    }
    return ret;
}

void UnselectAllSPI()
{
    UnSelect(CS_OPC);
    UnSelect(CS_ADC);
}

int Select(u32_t pin)
{
    UnselectAllSPI();

    int ret = gpio_pin_write(gpio_dev, pin, 0);
    if (ret)
    {
        LOG_ERR("Error writing to pin # %d", pin);
    }
    return ret;
}

int digitalWrite(u32_t pin, u32_t value)
{
    int ret = gpio_pin_write(gpio_dev, pin, value);
    if (ret)
    {
        LOG_ERR("Error writing %d to pin # %d", value, pin);
    }
    return ret;
}

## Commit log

2020-01-13 Hardware verification
    * Verified ADC SPI driver
    * verified CC2 driver
    * ported GPS code to zephyr
    * verified OPC-N3 communication
    * All I2C devices responds (still have to port the MAX14830 driver)
2020-01-13 Added a README
    and some images of the sensor node electronics
2020-01-14 Added step files for PCB stack
    [SensorPCB_stack.step]
2020-01-14 Added hardware design files
    [2_EE-10_and_SIM_AFE_Interface.SchDoc, EE-06-main-board.PrjPCB, HighPowerBoard_v2.PcbDoc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]
2020-01-15 Fixed timing bug after OPC data ready response
    * updated config (for math.h / atof)
    [opc_n3.c, opc_n3.h]
2020-01-16 Added enclosure README
2020-01-23 Uart multiplexer / buffer is now working in polled mode in zephyr * removed txrxbuffer.h/.c * fixed max14830 reset sequence * renamed stuff in i2c/spi config * added EE_NBIOT_01_RESET to gpio initial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
    [chipcap2.c, gpio.c, i2c_config.c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]
2020-01-23 Added uart interface for later use (fota)
2020-01-24 Added assembly for sensor innards
    [assembly-2-v10.f3z]
2020-01-29 Functional ADS124S08 driver
2020-01-30 Added STEP files for air nozzles
    [nozzle_bottom.step, nozzle_top.step]
2020-01-30 Corrected CS pin for OPC-N3 * CC2/OPC/ADC now running in main thread * Added messagebuffer * Removed redundant log messages
    [ads124s08.c, ads124s08.h, chipcap2.c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]
2020-02-03 Added message text encoding * Able to communicate with NBIoT module (some assembly required)
2020-02-04 Zephyr 2.1.0, FOTA, socket offloading
    Add necessary import and clean up prj.conf. Moved nRF5x options
    into boards/nrf52_pca10040.conf.
    Add versioning via Reto (config is TBD).
2020-02-04 Various cleanups
    Change printk -> printf
    Disable format overflow warning in n2_offload.c
2020-02-04 Move max14830 thread from main to max14830 source
    Keep thread declaration and creation with rest of code. The thread is now
    created when the semaphore is available so it's launched ASAP.
2020-02-05 First integration
    Fun fact: SPI can't be initialised from the network offloading function
    for reasons unknown.
2020-02-06 Include board when building MCUBoot
2020-02-06 Configure modem on startup
    Set APN to mda.ee and autoconnect to true.
    Also wait for the inital OK from the modem when it is powered up.
2020-02-06 Make semaphore for FOTA reboots
    Let the FOTA process run while data is sent. It should work.
    When there's time to reboot the semaphore is grabbed by the FOTA process
    and sampling will stop.
    [main.c]
2020-02-10 Added sensors and boxes
    [Alphasense-A4-AFE-3-way-v2.f3d, OPC-N3.f3d, TP-electric-3310-217-0600.f3d]
2020-02-10 Updated and renamed sensor block
    [Alphasense-A4-AFE-3-way-v2.f3d, Alphasense-A4-AFE-3-way.f3d]
2020-02-10 Hack for NSORF and MAX/SARA troubles, CoAP tokens
    Somewhere between the SARA N2 UART and the MAX-something chip there's
    some interesting interaction so the final OK for the NSORF is dropped.
    Stop processing when data is received and ignore the rest of the input.
    Also use secure random CoAP tokens.
2020-02-12 CMakeFile: Set current directory to absolute path
    Also print messages when building
2020-02-13 FOTA part II
    Block-wise transfers doesn't work ATM.
    [ads124s08.c, chipcap2.c]
2020-02-13 Remove sleep loop
    Turns out sleeping forever won't get you much sampling.
    Go figure.
    [main.c]
2020-02-26 First commit. Tool for listening to data from device.
2020-03-03 Fixed initialization of CC2 sensor * added missing OPC humidity field to message * added message hex dump (debug) output
    [chipcap2.c, main.c]
2020-03-05 Closed a few sockets.
2020-03-06 Change #include to support case sensitive FS
2020-03-09 Added sensor calculations
2020-03-20 Added calibration data
    [16-000158.csv, 16-000158.xls, 16-000159.csv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]
2020-03-23 Convenience script for importing calibration data
2020-03-24 Added show command to cal
    Also added serial numbers for afe sensors and circuit type. These
    were somehow forgotten along the way.
2020-03-24 Added JSON formatting to cal show, reverted mistake (use device IDs instead of entry ids)
2020-03-29 Tied together pipeline code and added calibration - Removed some of the noisy output
2020-04-03 Dropping devices table since we do not need it
2020-04-04 Added calibration data as JSON
    This is the format we support for distribution and only JSON files
    that have a valid device ID (Horde id) should be added here.
2020-04-05 Initial version of fetching of backlog data from Horde
    This will create duplicates if run more than once. Make sure you
    import the calibration data before you fetch data - the data is run
    through the processing pipeline where fields are calculated.
2020-04-26 Calibration data is now downloaded from S3 bucket on startup and then every 12 hours
2020-04-26 Added fetching of calibration data to fetch
2020-04-27 Added new calibration data
2020-04-27 re-added DeviceID after mistaken update (rest of cal files lack device id though)
2020-05-06 Fixed mapping of temp in messagebuf
    [main.c]
2020-05-06 Added STEP and STL files for PLA/PP parts
    [PLA_AFE_spacer.step, PLA_AFE_spacer.stl, PLA_OPC_hood_a.step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]
2020-05-12 Updated calibration data with device IDs, removed excel, csv, and scans
    [16-000158.csv, 16-000158.xls, 16-000159.csv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]
2020-05-18 Updated schematics and layout. Fixed missing common signal on ADC.
    [tk2.brd, tk2.sch]
2020-06-29 Point device to MIC
2020-06-29 Updated message format information Previous versions used just raw C-structs, but since this is fragile when things change we switched to protobuffers.
2020-07-14 Adding calibration data
2020-07-14 Renamed calibration data files
2020-07-14 Added preliminary MIC support to AQ
    Added preliminary MIC support to AQ. Note that MIC doesn't send us any metadata
    with our payload so we have to depend entirely on the payload from the device.
    Fortunately we can fix this by utilizing the sysid to uniquely identify the devices
    and look up the calibration data.
    Also included the calibration data in the repository since having to maintain
    an S3 bucket is not going to work as a long term solution.
    Listeners now have to be explicitly enabled with one of these
    command line options: --enable-mic or --enable-horde. The UDP
    listener only starts if you provide the --udp-listener with
    a listen address.
    Changed the miclistener code a bit so it ta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
2020-07-15 Populate DeviceID from calibration data when missing from datapoint.
    This is a workaround for when we use the MIC listener. The device ID
    gets lost because MIC doesn't propagate the metadata from the IoT-GW.
    This change also makes sure we can't start the server if a MIC
    listener is active but no credentials have been entered into
    the right environment variables.
2020-08-19 Added code to read calibration data from files locally
2020-08-20 Changed the way calibration data is handled.
    Rather than distributing the calibration data via AWS S3 we will now
    be distributing it by putting it in Github. This means that anyone operating
    an AQ server has to be a bit on their toes about updating the data themselves
    but it removes the burden of maintaining the calibration data from Telenor.
    On startup the AQ server will look for calibration data in the directory
    specified by the -m or --cal-data-dir command line options. By default this
    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
2020-09-25 NVS Storage and command protocol - part I
    * added initial version of config.proto for command protocol
    * added nanopb_generate for config-photo to CMakeLists.txt
    * fixed bug in makefile for target build_mcuboot
    * added watchdog
    * added non volatile storage of APN and COAP parameters
    * Fixed logging error in comms.c
    * resetting UDP port on modem restart
    * added timeouts to modem_restartxxx() and modem_init() in order to avoid infinite loops for non-responsive apps
    * made modem_configure() visible from outside comms.c
    * made fota_report_version visible from outside fota.c (used for weak COAP config validation)
    * added NVS initialisation to n2_init()
    * added NVS default parameters. Writing thes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
    [config.h, main.c]
2020-09-26 Implemnted two remote config commands * Set APN List command * Reboot command
    [config.h, main.c]
2020-09-28 Implemented flash storage of COAP params
    * Increased HEAP size and SACK size
    * COAP parameters are now selected form NVS
    * Fixed a bug in decoding of protobuf config messages
    [config.h, main.c]
2020-09-29 Now using protobufs with fixed array sizes
    [config.h, main.c]
2020-09-29 Minor bugfixes * Added a missing sys_reboot() * Increased timeouts for IP * Updated default APN list
    [config.h, main.c]
2020-10-01 Removed coap header for data messages
    * removed reboot after nvs config change
    [main.c]
2020-10-08 Fixed PING encoding
    * added PM1,PM2.5 and PM10 fields (decimal) to message
    [main.c]
2020-10-08 Make sure we print an error message if the calibration data directory does not exist
2021-02-19 Added calibration data for 5 additional sensors
